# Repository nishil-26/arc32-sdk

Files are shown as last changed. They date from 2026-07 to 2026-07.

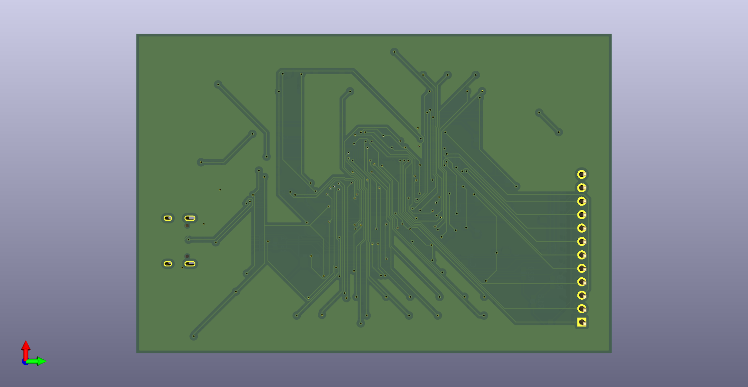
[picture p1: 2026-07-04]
hardware/renders/bottom_view.png

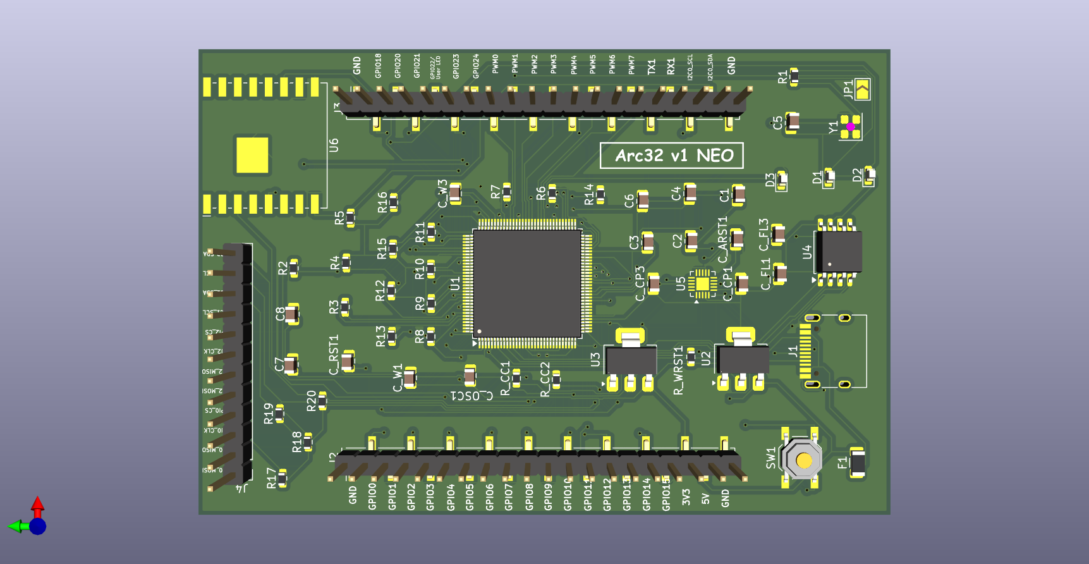
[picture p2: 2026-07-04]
hardware/renders/top_view.png

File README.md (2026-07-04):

#  Arc32 SDK & Hardware Ecosystem

This project encompasses both a high-performance physical development board designed in KiCad and a seamless Arduino Board Support Package (BSP) for zero-configuration software development.

Developed during an internship at **IIT Gandhinagar**, this project aims to make indigenous RISC-V silicon easily accessible to developers, students, and engineers worldwide.

---
## 🛠️ Hardware Overview

Arc32 v1 NEO is an open-source Arduino-compatible development board built around the indigenous **THEJAS32 SoC** (VEGA ET1031 RISC-V processor). The board combines native USB programming, onboard SPI Flash, integrated Wi-Fi/Bluetooth connectivity, and Arduino-style expansion headers into a compact development platform.

### ✨ Key Features

- **Processor:** THEJAS32 SoC (VEGA ET1031, 32-bit RISC-V RV32IM @ 100 MHz)
- **Memory:** 256 KB embedded SRAM + 2 MB W25Q16JVSS SPI NOR Flash
- **Wireless:** BW16 (RTL8720DN) module with Wi-Fi 4 and Bluetooth LE 5
- **USB Interface:** USB Type-C with onboard CP2102N USB-to-UART bridge
- **Power:** AMS1117-3.3V & AMS1117-1.2V regulators with 500 mA resettable polyfuse
- **Connectivity:** 24 GPIOs, PWM, UART, SPI, and I²C interfaces exposed through Arduino-compatible headers

## 📁 Hardware Resources

The complete hardware design is fully open-source and available under the `hardware/` directory.

```text
hardware/
└── arc32_v1_neo/
    ├── source_kicad/
    ├── production_files/
    └── renders/
```

###  `source_kicad/`
Contains the complete KiCad project for the board, including:
- Schematic (`.kicad_sch`)
- PCB Layout (`.kicad_pcb`)
- Project files (`.kicad_pro`)

These files can be edited directly using KiCad for customization or future revisions.

###  `production_files/`
Manufacturing-ready assets required for board fabrication and assembly:
- Gerber & Drill package (`.zip`)
- Bill of Materials (BOM)
- High-resolution schematic (PDF)
- Official Arc32 v1 NEO Datasheet

###  `renders/`
High-resolution 3D renders of the board, including:
- Top View
- Bottom View
- Angled Perspective
---

## Full Arduino-IDE board package for the Arc32 board:

## 🚀 Installation via Boards Manager (Recommended)

The easiest way to install the Arc32 SDK is through the Arduino IDE Boards Manager. This will automatically download the correct RISC-V GCC toolchain for your operating system (Windows, macOS, or Linux).

1. Open the Arduino IDE.
2. Go to **File** ➔ **Preferences** (on macOS: **Arduino** ➔ **Settings**).
3. In the **"Additional Boards Manager URLs"** field, paste the following link:
   ```text
   https://raw.githubusercontent.com/nishil-26/arc32-sdk/main/package_arc32_index.json
   ```

## Upload mode

- **Serial / UART (Default)**: JP1 jumper open. Default boot mode, used for
  programming via XMODEM over the CP2102N USB port.
- **SPI Flash (Standalone)**: JP1 jumper shorted. Board boots from the
  W25Q16 flash chip on every power-up (no need to be connected to a PC).

## Known limitations (v1.0)

- No `<algorithm>`/STL — `libstdc++` has no bare-metal rv32im port in this
  toolchain. Only the C++ language core + our own Print/Stream/String are
  available. Avoid `std::vector`, `std::function`, etc. in sketches.
- No floating point hardware — THEJAS32 has no FPU, all `float`/`double`
  math is done in software (slow but functional) via libgcc soft-float.
- `analogRead()` / ADC: THEJAS32 itself has no built-in ADC; the ARIES
  board used an external I2C ADC IC. Arc32 v1.0 does not yet include this
  — add an external ADC (e.g. ADS1115) over I2C0/I2C1 and use `Wire`
  directly until a dedicated `analogRead()` wrapper is written.
- SPI Flash direct upload not implemented — see Section 4 above.
- `INPUT_PULLUP` has no internal pull-up hardware on THEJAS32 GPIOs;
  treated as plain `INPUT` — add an external 10 KΩ pull-up resistor.

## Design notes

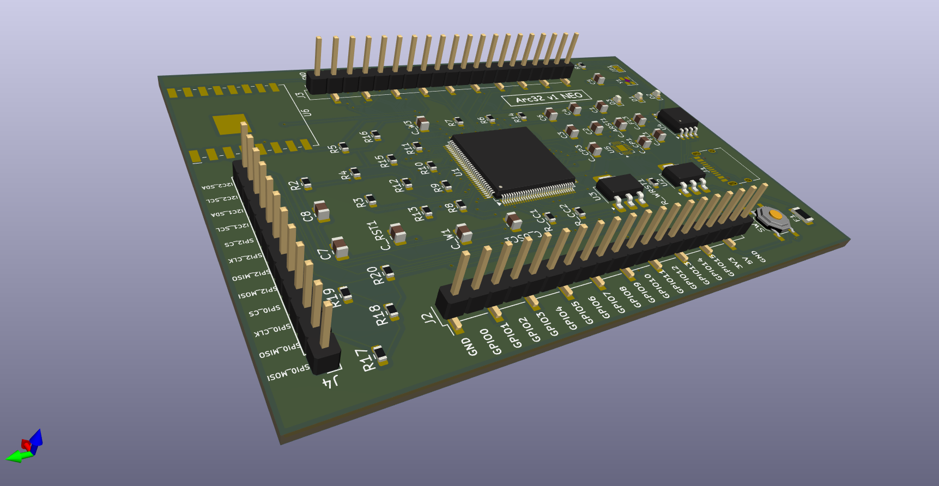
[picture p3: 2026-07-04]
hardware/renders/angled_view.png

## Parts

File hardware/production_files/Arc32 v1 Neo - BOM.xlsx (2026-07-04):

Designator | Component Description | Package | Qty | Unit Price | Total (INR) | Purchase Link
U1 | THEJAS32 SoC (VEGA ET1031) | LQFP-128 | 1 | ₹254.00 | ₹254.00 | C-DAC B2B Inquiry * (https://www.google.com/search?q=https://vegaprocessors.in/dev-boards/)
U6 | Ai-Thinker BW16 (RTL8720DN) Module | SMD-16 | 1 | ₹529.00 | ₹529.00 | ElectronicsComp (https://www.electronicscomp.com/ai-thinker-bw16-wifi-soc-module)
U5 | CP2102N USB-to-UART Bridge | QFN-20 | 1 | ₹241.00 | ₹241.00 | Robu.in (https://robu.in/product/cp2102n-a02-gqfn20r-skyworks-silicon-labs-3mbps-usb-to-uart-usb-2-0-qfn-20-ep3x3-usb-converters-rohs/)
U4 | W25Q16 (2MB SPI NOR Flash) | SOIC-8 | 1 | ₹35.00 | ₹35.00 | ElectronicsComp ** (https://www.google.com/search)
U2 | AMS1117-3.3V LDO Regulator | SOT-223 | 1 | ₹9.00 | ₹9.00 | Robu.in (https://robu.in/product/ams1117-3-3v-1a-sot-223-voltage-regulator-ic-pack-of-5-ics/)
U3 | AMS1117-1.2V LDO Regulator | SOT-223 | 1 | ₹9.00 | ₹9.00 | Robu.in (https://www.google.com/search)
J1 | USB Type-C Receptacle (16-Pin) | SMD | 1 | ₹12.00 | ₹12.00 | Robu.in (https://www.google.com/search?q=https://robu.in/product/type-c-usb-female-connector-smd-16-pin/)
J2, J3, J4 | 40-Pin Male Header (2.54mm) | THT | 2 | ₹9.00 | ₹18.00 | Robu.in (https://www.google.com/search)
Y1 | 16MHz SMD Crystal Oscillator | 3225 | 1 | ₹7.00 | ₹7.00 | Robu.in (https://www.google.com/search?q=https://robu.in/product/16mhz-crystal-oscillator-smd-3225-pack-of-5/)
SW1 | SMD Tactile Push Button | SMD | 1 | ₹3.00 | ₹3.00 | Robu.in (https://www.google.com/search?q=https://robu.in/product/smd-push-button-switch-6x6x4-3mm-pack-of-5/)
F1 | 500mA PTC Resettable Fuse | 1206 | 1 | ₹3.50 | ₹3.50 | Robu.in (https://www.google.com/search?q=https://robu.in/product/1206-smd-resettable-fuse-500ma-pack-of-10/)
D1-D3 | 0603 SMD LEDs (Power/User/HB) | 603 | 3 | ₹1.00 | ₹3.00 | Robu.in (https://www.google.com/search?q=https://robu.in/product/0603-smd-led-red-color-pack-of-50/)
R1-R20 | 0603 SMD Resistors (10kΩ) | 603 | 25 | ₹0.50 | ₹12.50 | Robu.in (https://www.google.com/search?q=https://robu.in/product/0603-smd-resistor-10k-ohm-pack-of-100/)
C1-C8 | 0603 SMD Capacitors (0.1µF) | 603 | 20 | ₹0.50 | ₹10.00 | Robu.in (https://www.google.com/search?q=https://robu.in/product/100nf-0-1uf-50v-smd-capacitor-0603-package/)
 |  |  |  | Total: | ₹1146.00

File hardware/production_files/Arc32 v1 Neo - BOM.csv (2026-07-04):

Designator | Component Description | Package | Qty | Unit Price | Total (INR) | Purchase Link
U1 | THEJAS32 SoC (VEGA ET1031) | LQFP-128 | 1 | ₹ 254.00 | ₹ 254.00 | C-DAC B2B Inquiry *
U6 | Ai-Thinker BW16 (RTL8720DN) Module | SMD-16 | 1 | ₹ 529.00 | ₹ 529.00 | ElectronicsComp
U5 | CP2102N USB-to-UART Bridge | QFN-20 | 1 | ₹ 241.00 | ₹ 241.00 | Robu.in
U4 | W25Q16 (2MB SPI NOR Flash) | SOIC-8 | 1 | ₹ 35.00 | ₹ 35.00 | ElectronicsComp **
U2 | AMS1117-3.3V LDO Regulator | SOT-223 | 1 | ₹ 9.00 | ₹ 9.00 | Robu.in
U3 | AMS1117-1.2V LDO Regulator | SOT-223 | 1 | ₹ 9.00 | ₹ 9.00 | Robu.in
J1 | USB Type-C Receptacle (16-Pin) | SMD | 1 | ₹ 12.00 | ₹ 12.00 | Robu.in
J2, J3, J4 | 40-Pin Male Header (2.54mm) | THT | 2 | ₹ 9.00 | ₹ 18.00 | Robu.in
Y1 | 16MHz SMD Crystal Oscillator | 3225 | 1 | ₹ 7.00 | ₹ 7.00 | Robu.in
SW1 | SMD Tactile Push Button | SMD | 1 | ₹ 3.00 | ₹ 3.00 | Robu.in
F1 | 500mA PTC Resettable Fuse | 1206 | 1 | ₹ 3.50 | ₹ 3.50 | Robu.in
D1-D3 | 0603 SMD LEDs (Power/User/HB) | 603 | 3 | ₹ 1.00 | ₹ 3.00 | Robu.in
R1-R20 | 0603 SMD Resistors (10kΩ) | 603 | 25 | ₹ 0.50 | ₹ 12.50 | Robu.in
C1-C8 | 0603 SMD Capacitors (0.1µF) | 603 | 20 | ₹ 0.50 | ₹ 10.00 | Robu.in
 |  |  |  | Total: | ₹ 1,146.00

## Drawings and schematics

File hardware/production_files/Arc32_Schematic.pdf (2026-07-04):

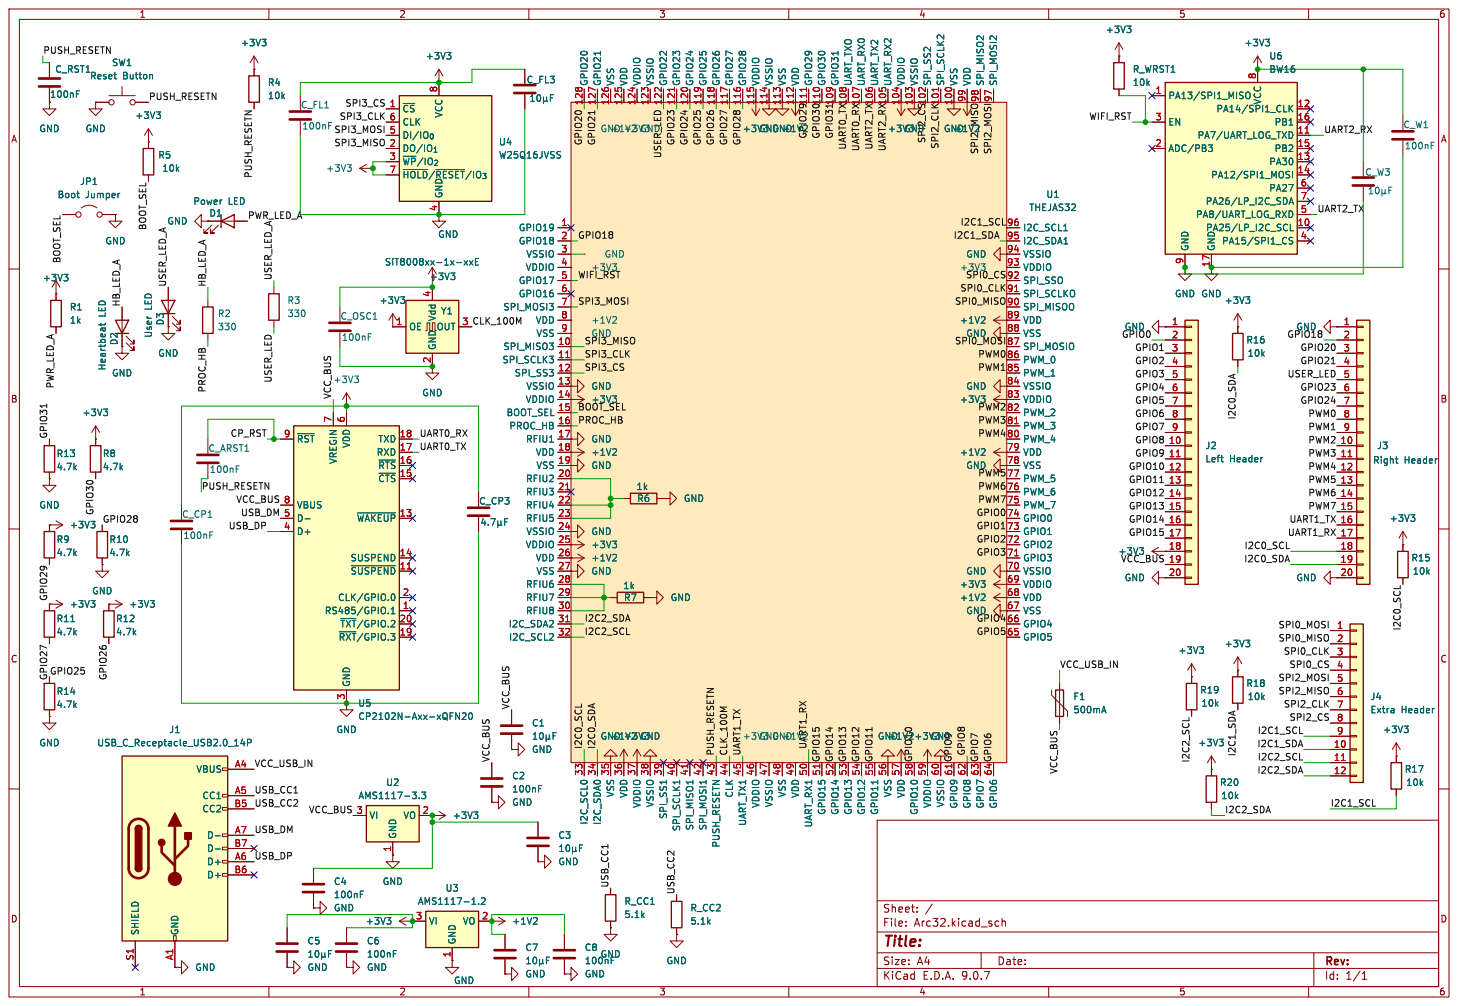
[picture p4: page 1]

8 PA14/SPI1_CLK 12 PB1 16 PA7/UART_LOG_TXD 11 PB2 15 PA30 13 PA12/SPI1_MOSI 14 PA27 6 PA26/LP_I2C_SDA 7 PA8/UART_LOG_RXD 5 PA25/LP_I2C_SCL 10 PA15/SPI1_CS 4 U6BW16 GND SHIELD S1 GND A1 VBUS A4 CC1 A5 CC2 B5 D- A7 D- B7 D+ A6 D+ B6

þÿ10µF U4 W25Q16JVSS
I2C_SDA1 95 VSSIO 94 VDDIO 93 SPI_SSO 92 SPI_SCLKO 91 SPI_MISOO 90 VDD 89 VSS 88 SPI_MOSIO 87 PWM_0 86 PWM_1 85 VSSIO 84 VDDIO 83 PWM_2 82 PWM_3 81 PWM_4 80 VDD 79 VSS 78 PWM_5 77 PWM_6 76 PWM_7 75 GPIO0 74 GPIO1 73 GPIO2 72 GPIO3 71 VSSIO 70 VDDIO 69 VDD 68 VSS 67 GPIO4 66 GPIO5 65 GND+1V2 +3V3GND

J3 Right Header +3V3 D1 Power LED

2 OUT 3 U5 CP2102N-Axx-xQFN20 ~{RST} 9 VBUS 8 D- 5 D+ 4 VREGIN

3 TXD 18 RXD 17 ~{RTS} 16 ~{CTS} 15 ~{WAKEUP} 13 SUSPEND 14 ~{SUSPEND}11 CLK/GPIO.0 2 RS485/GPIO.1 1 ~{TXT}/GPIO.220 ~{RXT}/GPIO.319 U5 CP2102N-Axx-xQFN20 GND GND

3 TXD 18 RXD 17 ~{RTS} 16 ~{CTS} 15 ~{WAKEUP} 13 SUSPEND 14 ~{SUSPEND}11 CLK/GPIO.0 2 RS485/GPIO.1 1 ~{TXT}/GPIO.220 ~{RXT}/GPIO.319 GND

Id: 1/1 Title: File: Arc32.kicad_sch Sheet: /

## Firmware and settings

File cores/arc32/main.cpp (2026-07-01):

/*
 * main.cpp  —  Arc32 Arduino Core Entry Point
 *
 * Called from _start (startup.S) after .bss/.data are set up.
 * Runs C++ static constructors, calls init() for hardware bring-up,
 * then calls the sketch's setup() once and loop() forever.
 */

#include "Arduino.h"

extern "C" {
    /* Provided by linker script */
    extern void (*__init_array_start[])(void);
    extern void (*__init_array_end[])(void);

    int main(void)
    {
        /* ---- Run C++ global object constructors ---- */
        for (void (**ctor)(void) = __init_array_start;
             ctor < __init_array_end; ctor++)
        {
            (*ctor)();
        }

        /* ---- Hardware bring-up: TIMER0 for millis(), PLIC, IRQ enable ---- */
        init();

        /* ---- User sketch ---- */
        setup();

        for (;;) {
            loop();
        }

        return 0;   /* never reached */
    }
}

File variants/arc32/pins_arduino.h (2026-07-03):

/*
 * pins_arduino.h  —  Arc32 Pin Mapping
 *
 * Maps Arduino logical pin numbers to THEJAS32 GPIO banks / PWM channels.
 *
 * Physical header layout 
 *
 *   J2 LEFT HEADER          J3 RIGHT HEADER
 *   ─────────────           ───────────────
 *   1  GND                  1  GND
 *   2  D0  (GPIO0)          2  D16 (GPIO18)
 *   3  D1  (GPIO1)          3  D17 (GPIO20)
 *   4  D2  (GPIO2)          4  D18 (GPIO21)
 *   5  D3  (GPIO3)          5  D19 (GPIO22/LED)
 *   6  D4  (GPIO4)          6  D20 (GPIO23)
 *   7  D5  (GPIO5)          7  D21 (GPIO24)
 *   8  D6  (GPIO6)          8  D22 (PWM0)
 *   9  D7  (GPIO7)          9  D23 (PWM1)
 *   10 D8  (GPIO8)          10 D24 (PWM2)
 *   11 D9  (GPIO9)          11 D25 (PWM3)
 *   12 D10 (GPIO10)         12 D26 (PWM4)
 *   13 D11 (GPIO11)         13 D27 (PWM5)
 *   14 D12 (GPIO12)         14 D28 (PWM6)
 *   15 D13 (GPIO13)         15 D29 (PWM7)
 *   16 D14 (GPIO14)         16 TX1 (UART1_TX)
 *   17 D15 (GPIO15)         17 RX1 (UART1_RX)
 *   18 3V3                  18 SCL (I2C0_SCL)
 *   19 5V                   19 SDA (I2C0_SDA)
 *   20 GND                  20 GND
 *
 *   J4 EXTRA HEADER
 *   ───────────────
 *   1  SPI0_MOSI            7  SPI2_CLK
 *   2  SPI0_MISO            8  SPI2_CS
 *   3  SPI0_CLK             9  I2C1_SCL
 *   4  SPI0_CS              10 I2C1_SDA
 *   5  SPI2_MOSI            11 I2C2_SCL
 *   6  SPI2_MISO            12 I2C2_SDA
 */

#ifndef PINS_ARDUINO_H
#define PINS_ARDUINO_H

#include "thejas32.h"

/* -----------------------------------------------------------------------
 * Total pin count
 * ----------------------------------------------------------------------- */
#define NUM_DIGITAL_PINS    30   /* D0..D29                                   */
#define NUM_ANALOG_INPUTS    0   /* No on-chip ADC in THEJAS32 (ext ADC TBD)  */

/* -----------------------------------------------------------------------
 * Pin type enumeration (for pin descriptor table)
 * ----------------------------------------------------------------------- */
typedef enum {
    PIN_TYPE_GPIO0 = 0,  /* In GPIO0 bank (GPIO0–GPIO15)                     */
    PIN_TYPE_GPIO1,      /* In GPIO1 bank (GPIO16–GPIO31)                    */
    PIN_TYPE_PWM,        /* Dedicated PWM output (PWM controller)            */
} PinType;

/* -----------------------------------------------------------------------
 * Pin descriptor: bank + bit within that bank for GPIO,
 *                 channel index for PWM
 * ----------------------------------------------------------------------- */
typedef struct {
    PinType   type;
    uint8_t   bit;       /* bit position in GPIO0/GPIO1 DR/DDR/EXT           */
                         /* or PWM channel number for PWM pins               */
} PinDesc;
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

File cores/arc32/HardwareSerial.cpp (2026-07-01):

/*
 * HardwareSerial.cpp  —  Arc32 UART Driver
 *
 * Supports UART0 (Serial  – CP2102N USB), 
 *           UART1 (Serial1 – J3 header),
 *           UART2 (Serial2 – RTL8720DN WiFi).
 *
 * TX: polling (writes directly to THR when THRE=1).
 * RX: interrupt-driven with 256-byte circular ring buffer.
 */

#include "HardwareSerial.h"

/* -----------------------------------------------------------------------
 * Ring buffer
 * ----------------------------------------------------------------------- */
#define SERIAL_RX_BUF 256   /* must be power of 2 */
#define SERIAL_TX_BUF 64

struct RingBuf {
    volatile uint8_t buf[SERIAL_RX_BUF];
    volatile uint16_t head;
    volatile uint16_t tail;
};

static inline bool rb_empty(const struct RingBuf *rb) {
    return rb->head == rb->tail;
}
static inline bool rb_full(const struct RingBuf *rb) {
    return ((rb->head + 1) & (SERIAL_RX_BUF - 1)) == rb->tail;
}
static inline void rb_push(struct RingBuf *rb, uint8_t b) {
    if (!rb_full(rb)) {
        rb->buf[rb->head] = b;
        rb->head = (rb->head + 1) & (SERIAL_RX_BUF - 1);
    }
    /* if full, byte is dropped (overrun) */
}
static inline int rb_pop(struct RingBuf *rb) {
    if (rb_empty(rb)) return -1;
    uint8_t b = rb->buf[rb->tail];
    rb->tail = (rb->tail + 1) & (SERIAL_RX_BUF - 1);
    return b;
}

/* Per-UART state */
struct UARTState {
    uint32_t      base;
    struct RingBuf rx;
    uint8_t       irq;
};

static struct UARTState _uart[3] = {
    { UART0_BASE, {{0},0,0}, IRQ_UART0 },
    { UART1_BASE, {{0},0,0}, IRQ_UART1 },
    { UART2_BASE, {{0},0,0}, IRQ_UART2 },
};

/* -----------------------------------------------------------------------
 * Low-level UART helpers
 * ----------------------------------------------------------------------- */
static void _uart_set_baud(uint32_t base, uint32_t baud)
{
    uint32_t div = UART_BAUD_DIV(baud);
    /* Enable divisor latch access */
    UART_REG(base, UART_LCR_OFF) = UART_LCR_DLAB;
    UART_REG(base, UART_DLL_OFF) = div & 0xFF;
    UART_REG(base, UART_DLH_OFF) = (div >> 8) & 0xFF;
    /* 8N1, disable DLAB */
    UART_REG(base, UART_LCR_OFF) = UART_LCR_WLS_8;
}

static void _uart_hw_init(uint32_t base, uint32_t baud)
{
    _uart_set_baud(base, baud);
    /* Enable and clear FIFOs, RX trigger = 1 byte */
    UART_REG(base, UART_FCR_OFF) =
        UART_FCR_FIFOEN | UART_FCR_RXCLR | UART_FCR_TXCLR | UART_FCR_RXTRIG_1;
    /* Enable RX interrupt only */
    UART_REG(base, UART_IER_OFF) = UART_IER_RDI;
}

static inline bool _uart_tx_ready(uint32_t base) {
    return (UART_REG(base, UART_LSR_OFF) & UART_LSR_THRE) != 0;
}
static inline bool _uart_rx_ready(uint32_t base) {
    return (UART_REG(base, UART_LSR_OFF) & UART_LSR_DR) != 0;
}
static inline void _uart_tx_byte(uint32_t base, uint8_t b) {
    while (!_uart_tx_ready(base));
    UART_REG(base, UART_THR_OFF) = b;
}

/* -----------------------------------------------------------------------
 * UART RX ISR (called from trap handler per UART index)
 * ----------------------------------------------------------------------- */
static void _uart_rx_isr(uint8_t idx)
{
    struct UARTState *u = &_uart[idx];
    /* Drain the RX FIFO */
    while (_uart_rx_ready(u->base)) {
        uint8_t b = (uint8_t)UART_REG(u->base, UART_RBR_OFF);
        rb_push(&u->rx, b);
    }
}
void _uart0_isr(void) { _uart_rx_isr(0); }
void _uart1_isr(void) { _uart_rx_isr(1); }
void _uart2_isr(void) { _uart_rx_isr(2); }

/* -----------------------------------------------------------------------
 * HardwareSerial implementation
 * ----------------------------------------------------------------------- */
HardwareSerial::HardwareSerial(uint8_t uart_idx)
    : _idx(uart_idx), _baud(0) {}

void HardwareSerial::begin(uint32_t baud)
{
    _baud = baud;
    struct UARTState *u = &_uart[_idx];
    _uart_hw_init(u->base, baud);

    /* Enable IRQ in PLIC */
    PLIC_SET_PRIORITY(u->irq, 1);
    PLIC_ENABLE_IRQ(u->irq);
    csr_set(mie, MIE_MEIE);
    csr_set(mstatus, MSTATUS_MIE);
}

void HardwareSerial::begin(uint32_t baud, uint8_t config)
{
    /* config byte: low nibble = bits, upper nibble = parity/stop (future)  */
    (void)config;
    begin(baud);
}

void HardwareSerial::end(void)
{
    /* Flush TX, disable RX interrupt */
    flush();
    UART_REG(_uart[_idx].base, UART_IER_OFF) = 0;
    PLIC_DISABLE_IRQ(_uart[_idx].irq);
    _baud = 0;
}

int HardwareSerial::available(void)
{
    struct UARTState *u = &_uart[_idx];
    disable_irq();
    int n = (u->rx.head - u->rx.tail) & (SERIAL_RX_BUF - 1);
    enable_irq();
    return n;
}

int HardwareSerial::peek(void)
{
    struct UARTState *u = &_uart[_idx];
    if (rb_empty(&u->rx)) return -1;
    return u->rx.buf[u->rx.tail];
}

int HardwareSerial::read(void)
{
    disable_irq();
    int b = rb_pop(&_uart[_idx].rx);
    enable_irq();
    return b;
}
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

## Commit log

2026-07-01 Add Arduino.h header for Arc32 Arduino Core
2026-07-01 Create pins_arduino.h for Arc32 pin mapping
    Add pin mapping for Arc32 microcontroller to Arduino framework.
2026-07-01 Add arc32_upload.py for XMODEM file upload
    This script implements the XMODEM protocol to upload a compiled .bin file over UART0 to THEJAS32 SRAM, including functionalities for serial communication and error handling.
    [arc32_upload.py]
2026-07-01 Add Blink example for Arc32 board
    This example blinks the on-board User LED on the Arc32 board.
2026-07-01 Add I2C Scanner example for Arc32
    This sketch scans the I2C0 bus for connected devices and prints their addresses.
2026-07-02 Add Blink example for Arc32 (THEJAS32)
    This example demonstrates how to blink the on-board User LED on the Arc32 (THEJAS32).
2026-07-02 Create SerialEcho example for UART0 communication
    Added SerialEcho example to demonstrate UART0 communication.
2026-07-02 Refactor Arc32 platform definition for Arduino IDE
2026-07-04 Rename schematic file to arc32_v1_neo.kicad_sch
    [arc32_v1_neo.kicad_sch]
2026-07-04 Enhance README with hardware details and resources
    Expanded hardware overview and specifications for the Arc32 v1 NEO development board, detailing key features and resources.
